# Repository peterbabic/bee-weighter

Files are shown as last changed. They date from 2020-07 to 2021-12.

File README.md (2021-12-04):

# Bee weighter

The data the testing run harvested are available in
[data.ods](./docs/data.ods). An excerpt:

```
674488892	14		16.05.2021 14:01:32
674488895	7			16.05.2021 14:01:35
674489230	0			16.05.2021 14:07:10
674489233	1			16.05.2021 14:07:13
674489236	5165	16.05.2021 14:07:16
674489239	-181	16.05.2021 14:07:19
674489242	-139	16.05.2021 14:07:22
674489245	-93		16.05.2021 14:07:25
674489258	2			16.05.2021 14:07:38
674489261	5			16.05.2021 14:07:41
674489264	9			16.05.2021 14:07:44
```

## Quadruple strain

Using four single strain half bridges together again forms a full bridge,
with the resistance doubled. **200kg max.**

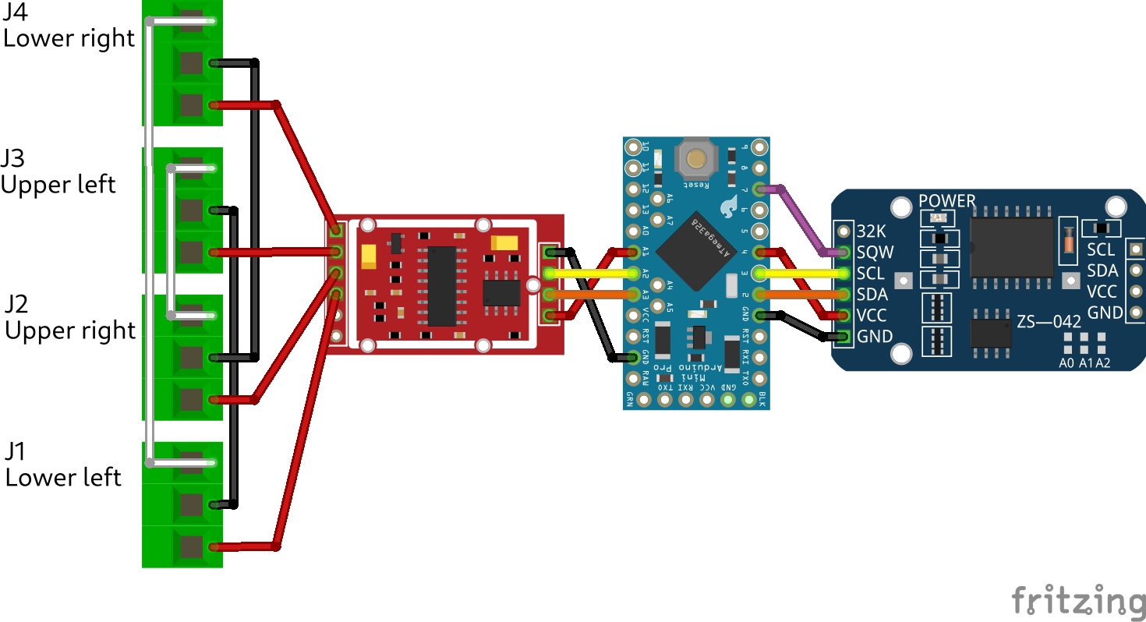
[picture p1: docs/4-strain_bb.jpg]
Two single strain half bridges togerher breadboard view


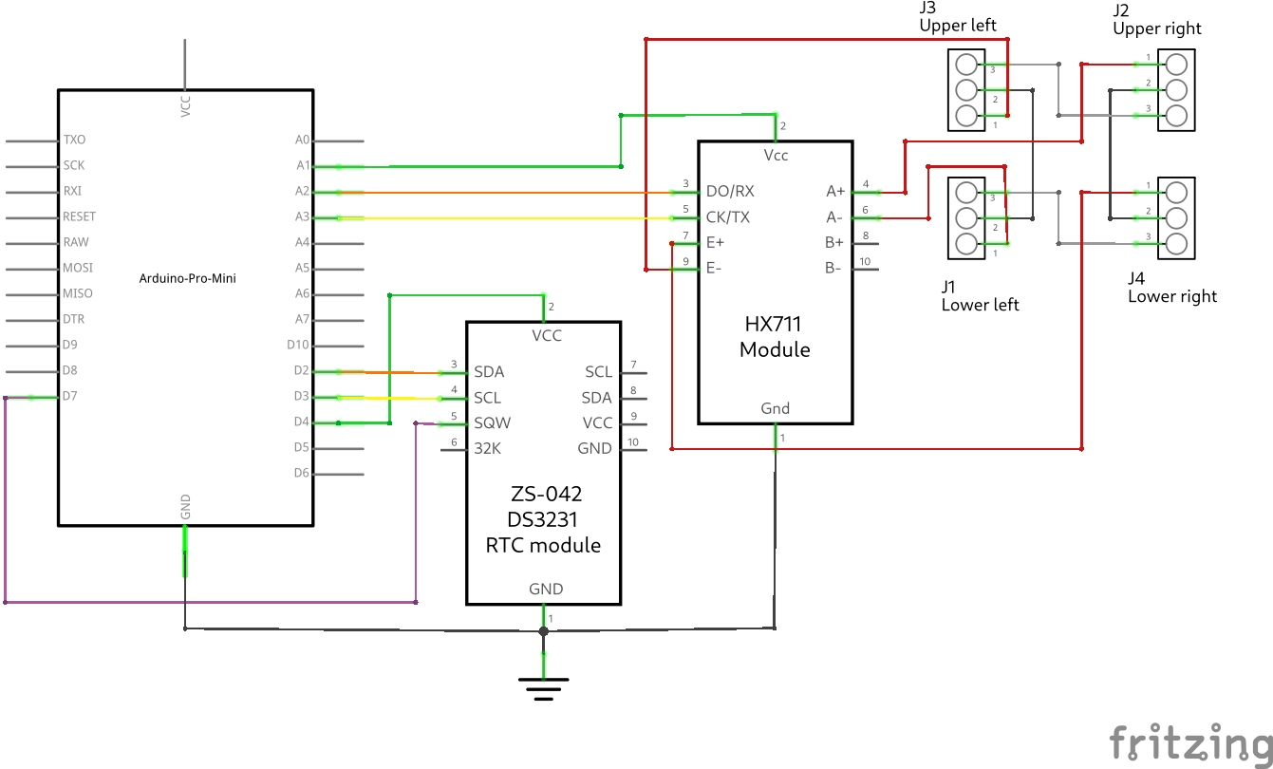
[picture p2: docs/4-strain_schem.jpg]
Two single strain half bridges togerher breadboard schematic


## Bottom side

The bottom side for testing looked like this initially:
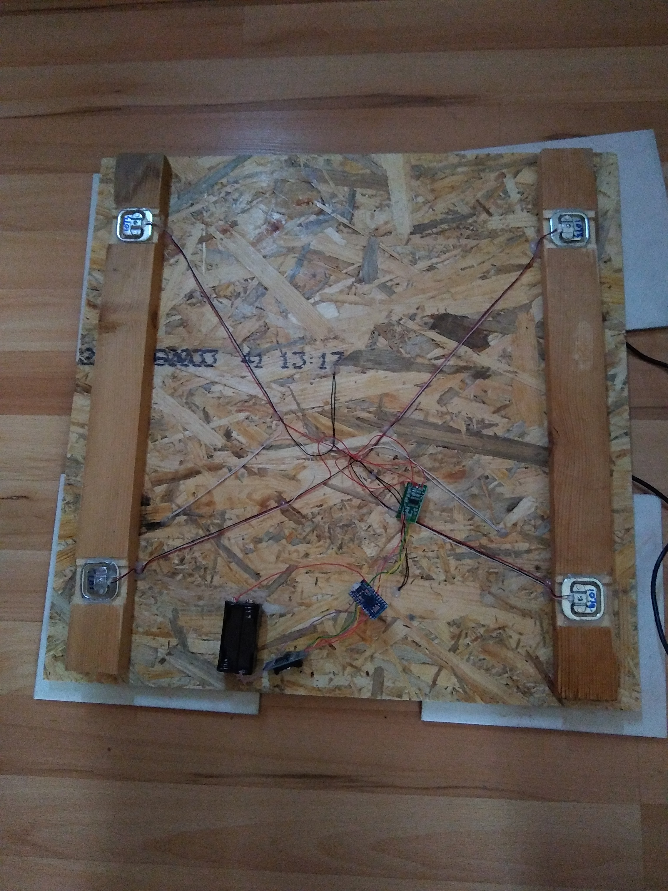
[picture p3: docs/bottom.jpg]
The bottom side of the weighting platform


## Commands

Load the code into the Arduino Pro Micro 3.3V:

```
pio run -t upload
```

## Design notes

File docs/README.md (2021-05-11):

# Strain connections

## Single strain

Individual strain consists of two 1k resistors connected as a voltage
divider. Connection with two fixed 1k resistors as a voltage divider
creates a full bridge. **50kg max.**

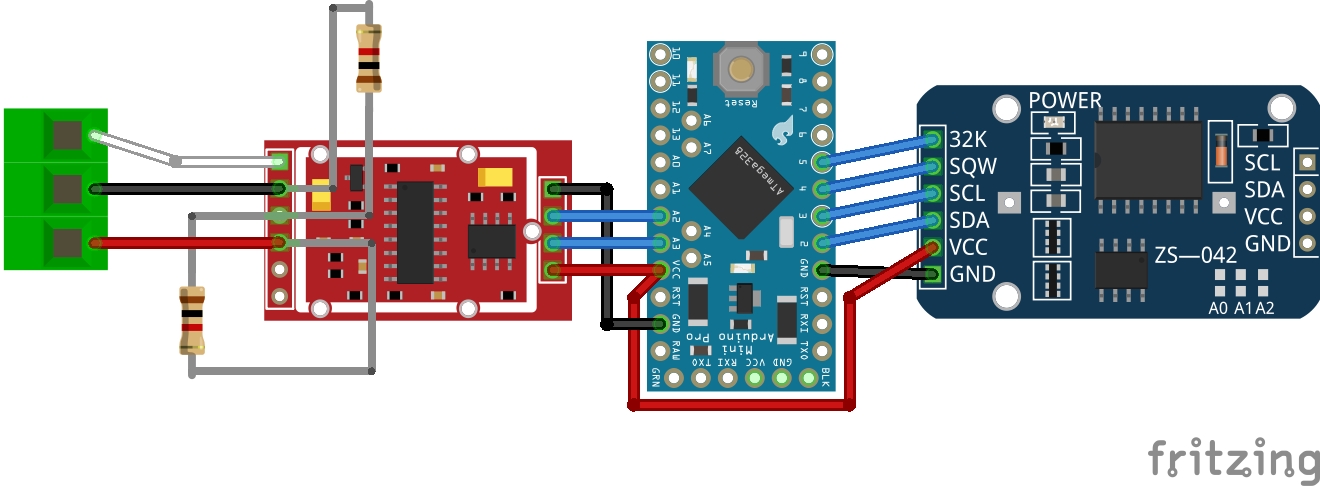
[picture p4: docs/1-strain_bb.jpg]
Single strain half bridge with two additional 1k resistors breadboard view


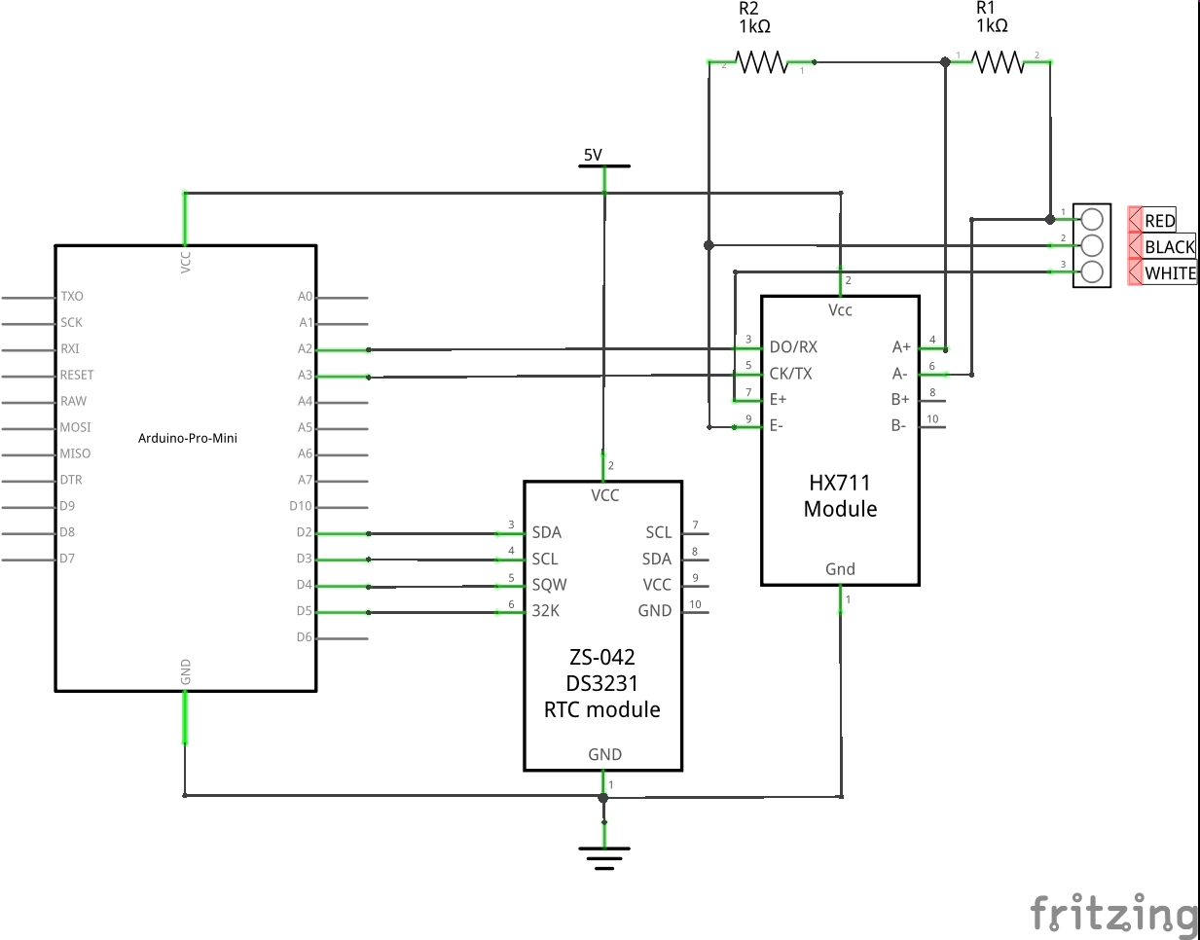
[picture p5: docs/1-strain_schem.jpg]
Single strain half bridge with two additional 1k resistors schematic


## Double strain

Using two single strain half bridges together forms a full bridge. **100kg
max.**

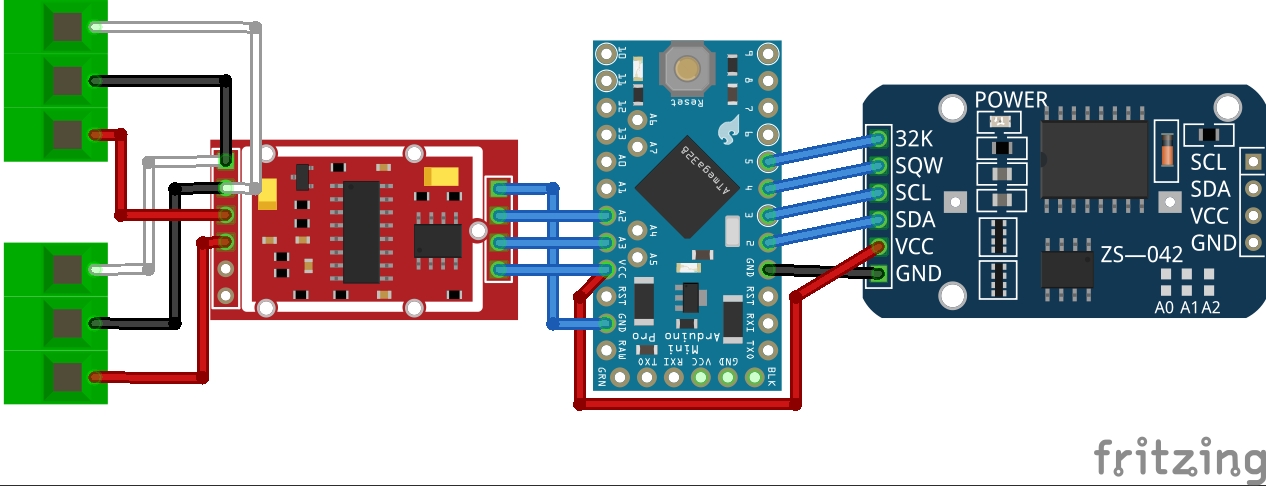
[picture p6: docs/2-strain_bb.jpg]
Two single strain half bridges togerher breadboard view


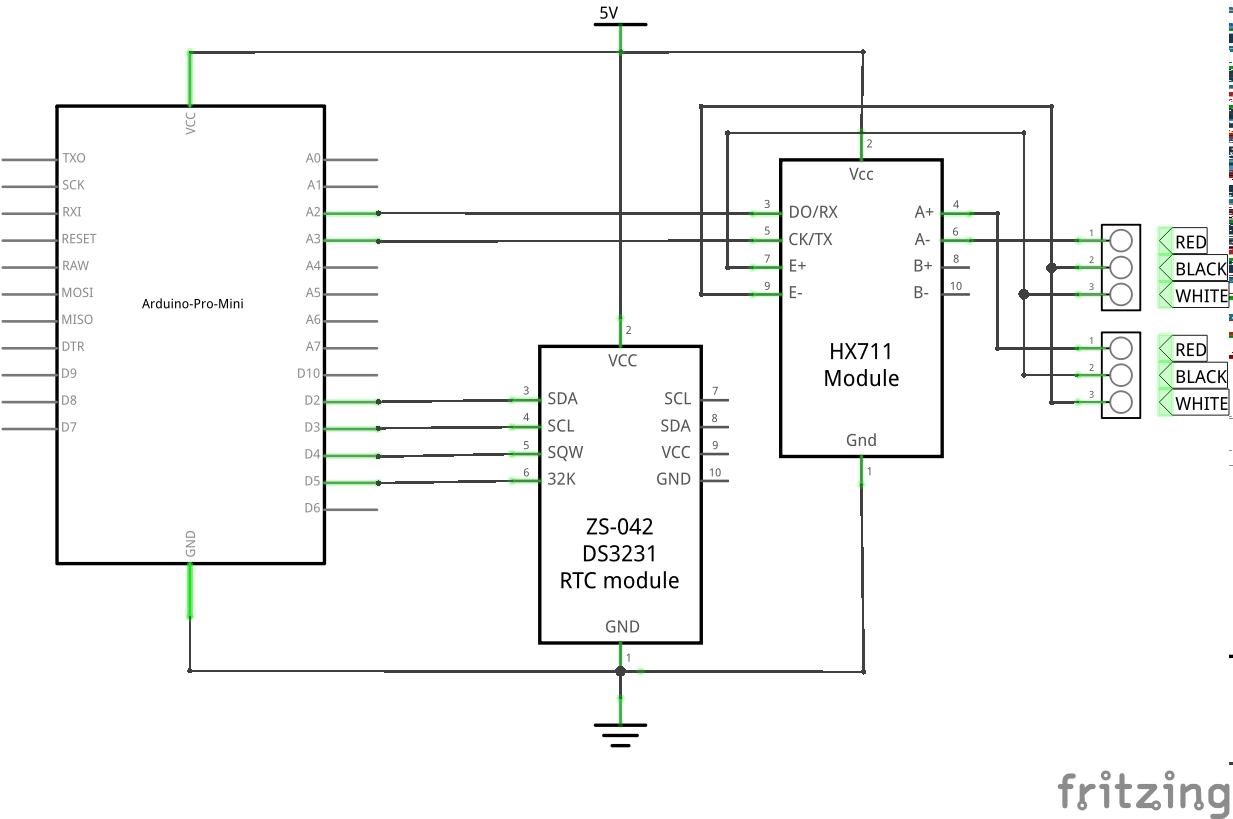
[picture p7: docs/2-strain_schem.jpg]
Two single strain half bridges togerher breadboard schematic


## Quadruple strain

Using four single strain half bridges together again forms a full bridge,
with the resistance doubled. **200kg max.**

Two single strain half bridges togerher breadboard view

Two single strain half bridges togerher breadboard schematic

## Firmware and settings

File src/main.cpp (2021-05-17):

#include <Arduino.h>
#include <avr/sleep.h>

#include <Wire.h>
#include <RtcDS3231.h>
#include <HX711.h>
#include <EepromAT24C32.h>

#define countof(a) (sizeof(a) / sizeof(a[0]))

RtcDS3231<TwoWire> Rtc(Wire);
EepromAt24c32<TwoWire> RtcEeprom(Wire);
HX711 scale;

const float COEFF = 0.2157f;

const int rtcPowerPin = 4;
const int wakeUpPin = 7;
const int ledPin = 17;

const int scaleDataPin = 21;
const int scaleSckPin = 20;
const int scalePowerPin = 19;

const int secondsTillNextWakeup = 21600;
const long interval = 50;

const int memTotal = 4096;
const int pageSize = 16;
const int pageCount = (memTotal / pageSize) - 1;

void wake()
{
    sleep_disable();
    detachInterrupt(digitalPinToInterrupt(wakeUpPin));
}

void sleepNow()
{
    set_sleep_mode(SLEEP_MODE_PWR_DOWN);
    noInterrupts();
    sleep_enable();
    attachInterrupt(digitalPinToInterrupt(wakeUpPin), wake, LOW);
    interrupts();
    sleep_cpu();
}

void setup()
{
    delay(15000);

    Serial.begin(9660);
    Serial.println();

    pinMode(wakeUpPin, INPUT_PULLUP);
    pinMode(ledPin, OUTPUT);
    pinMode(scalePowerPin, OUTPUT);

    pinMode(rtcPowerPin, OUTPUT);
    digitalWrite(rtcPowerPin, HIGH);
    digitalWrite(scalePowerPin, HIGH);

    Rtc.Begin();
    RtcEeprom.Begin();

    scale.begin(scaleDataPin, scaleSckPin);
    scale.set_scale(1000.f); 
    scale.tare();            

    RtcDateTime compiled = RtcDateTime(__DATE__, __TIME__);

    if (!Rtc.IsDateTimeValid())
    {
        if (Rtc.LastError() != 0)
        {
            Serial.print("RTC communications error = ");
            Serial.println(Rtc.LastError());
        }
        else
        {
            Serial.println("RTC lost confidence in the DateTime!");
            Rtc.SetDateTime(compiled);
        }
    }

    if (!Rtc.GetIsRunning())
    {
        Serial.println("RTC was not actively running, starting now");
        Rtc.SetIsRunning(true);
    }

    RtcDateTime now = Rtc.GetDateTime();
    if (now < compiled)
    {
        Serial.println("RTC is older than compile time!  (Updating DateTime)");
        Rtc.SetDateTime(compiled);
    }

    Rtc.Enable32kHzPin(false);
    Rtc.SetSquareWavePin(DS3231SquareWavePin_ModeAlarmOne);

    // const char data[] = "0               ";
    // for (int i = 0; i <= pageCount; i++)
    // {
    //     RtcEeprom.SetMemory(i * pageSize, (const uint8_t *)data, sizeof(data) - 1); // remove the null terminator strings add
    //     Serial.print('.');
    // }

    for (int i = 0; i <= pageCount; i++)
    {
        uint8_t buff[pageSize + 1];
        uint8_t gotten = RtcEeprom.GetMemory(i * pageSize, buff, pageSize);
        for (uint8_t ch = 0; ch < gotten; ch++)
        {
            Serial.print((char)buff[ch]);
        }
        Serial.println();
    }

    delay(15000);
}

void loop()
{
    pinMode(rtcPowerPin, OUTPUT);
    pinMode(scalePowerPin, OUTPUT);
    digitalWrite(scalePowerPin, HIGH);
    digitalWrite(rtcPowerPin, HIGH);
    digitalWrite(ledPin, LOW);

    delay(interval);

    scale.power_up();

    RtcDateTime now = Rtc.GetDateTime();
    RtcDateTime alarmTime = now + secondsTillNextWakeup;
    DS3231AlarmOne alarm1(
        alarmTime.Day(),
        alarmTime.Hour(),
        alarmTime.Minute(),
        alarmTime.Second(),
        DS3231AlarmOneControl_HoursMinutesSecondsMatch);

    Rtc.SetAlarmOne(alarm1);
    Rtc.LatchAlarmsTriggeredFlags();

    uint16_t highest = 0;
    uint32_t highestEpoch = 0;
    uint8_t epochBuff[40];

    for (int i = 0; i <= pageCount; i++)
    {
        uint16_t epochGotten = RtcEeprom.GetMemory(i * pageSize, epochBuff, 10);
        uint32_t epoch = strtol((const char *)epochBuff, NULL, 0);

        if (epoch > highestEpoch)
        {
            highest = i;
            highestEpoch = epoch;
        }
    }

    char memString[pageSize + 1];
    int16_t weight = scale.get_units(1) / COEFF;
    snprintf_P(memString, countof(memString), PSTR("%10ld%6d"), now.TotalSeconds(), weight);

    uint16_t head = (highest + 1) % (pageCount + 1);
    RtcEeprom.SetMemory(head * pageSize, (const uint8_t *)memString, pageSize);

    // Serial.println(memString);

    Serial.flush();
    scale.power_down();

    digitalWrite(scalePowerPin, LOW);
    digitalWrite(ledPin, HIGH);
    digitalWrite(rtcPowerPin, LOW);
    pinMode(rtcPowerPin, INPUT);
    pinMode(scalePowerPin, INPUT);

    sleepNow();
}

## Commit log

2020-07-28 split strains and move to docs
    [1-strain.fzz, 2-strain.fzz]
2020-07-28 finalize schematics
    [1-strain.fzz, 2-strain.fzz]
2020-07-28 add docs about schematics
2021-01-26 fix 2-strain breadboard color
    [2-strain.fzz, bee-weighter.fzz]
2021-01-26 insert quadruple strain
    [4-strain.fzz]
2021-05-10 interrupt once per second
2021-05-11 power the rtc via pin
2021-05-11 update strain docs
    [4-strain.fzz]
2021-05-11 include temperature
2021-05-11 fix schematic wire colors
    [4-strain.fzz]
2021-05-17 convert calibrate the dekagrams weight
2021-05-18 insert example data
    [data.ods]
